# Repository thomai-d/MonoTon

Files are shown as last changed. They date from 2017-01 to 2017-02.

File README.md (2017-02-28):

# MonoTon
Arduino based step sequencer and software-synth

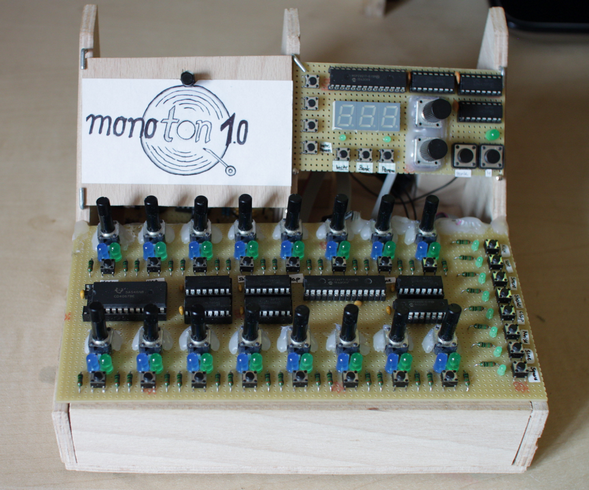
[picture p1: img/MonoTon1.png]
MonoTon1


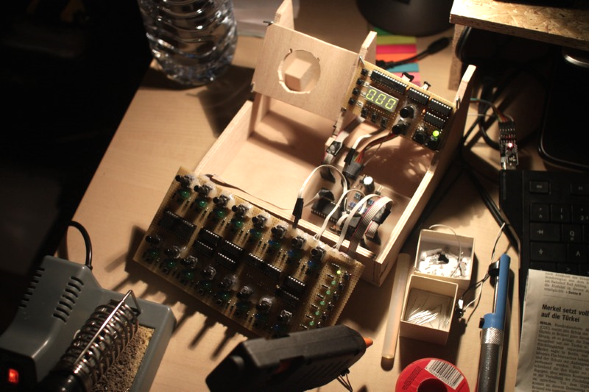
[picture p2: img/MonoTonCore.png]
MonotonCore


Video on youtube:

Youtube (http://www.youtube.com/watch?v=V6P4GdR-m2A)

[(Audio only)](https://github.com/thomai-d/MonoTon/blob/master/media/MonoTon1.mp3).

## Features
* 8 instruments (Kick, Hat, Snare, Shaker, Clap, Noise, Sine, Square)
* Each instrument has 4 banks a 16 steps each and can be muted
* Synthesis using 8bit wavetables
* 20000Hz sampling rate
* Master is filtered through analog high-pass filter (2pole)

## Hardware
* atmega1284 @ 16MHz using [Mighty1284 platform](https://github.com/maniacbug/mighty-1284p)
* lots of 74HC595 shift registers (for LEDs)
* MCP23S17 port extenders (for buttons)
* CD4067 multiplexer (for analog potis)
* R2R network for D/A conversion
* Some eagle files included

## Lessons learned while developing
* The analog inputs are quite noisy. De-noising uses quite much cpu.
* Don't ever solder this much wires by hand. PCB services are your friend.
* Prefer [DDS](http://interface.khm.de/index.php/lab/interfaces-advanced/arduino-dds-sinewave-generator/) over an R2R ladder.

## Open bugs / flaws
* Although the output is buffered by an opamp, the sound sounds distorted when using the PC's line in. If I conntect it directly to the speakers, the sound is quite clear.

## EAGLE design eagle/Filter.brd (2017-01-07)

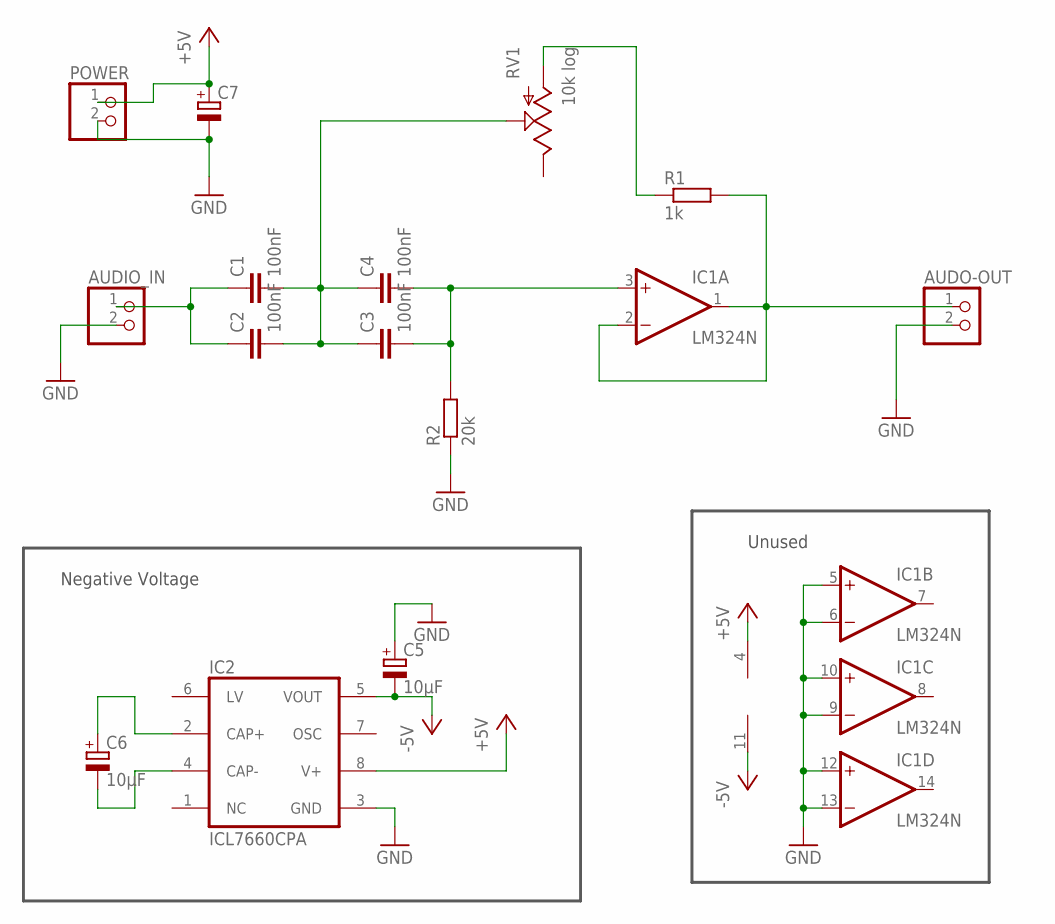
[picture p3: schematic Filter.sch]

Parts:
AUDIO_IN: PINHD-1X2; 1X02
AUDO-OUT: PINHD-1X2; 1X02
C1, C2, C3, C4: 100nF; C025-025X050
C5, C6: 10µF; E2,5-6
C7: CPOL-EUE2.5-6; E2,5-6
IC1: LM324N; DIL14
IC2: ICL7660CPA; DIL08
POWER: PINHD-1X2; 1X02
R1: 1k; 0207/7
R2: 20k; 0207/7
RV1: 10k log; ALPS_POT

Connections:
+5V: C7.+, IC1.4 (V+), IC2.8 (V+), POWER.1
-5V: C5.-, IC1.11 (V-), IC2.5 (VOUT)
GND: AUDIO_IN.2, AUDO-OUT.2, C5.+, C7.-, IC1.5 (+IN), IC1.6 (-IN), IC1.9 (-IN), IC1.10 (+IN), IC1.12 (+IN), IC1.13 (-IN), IC2.3 (GND), POWER.2, R2.1
unnamed: C3.2, C4.2, IC1.3 (+IN), R2.2
unnamed: AUDIO_IN.1, C1.1, C2.1
unnamed: C1.2, C2.2, C3.1, C4.1, RV1.P$2 (S)
unnamed: AUDO-OUT.1, IC1.1 (OUT), IC1.2 (-IN), R1.2
unnamed: R1.1, RV1.P$3 (A)
unnamed: C6.+, IC2.2 (CAP+)
unnamed: C6.-, IC2.4 (CAP-)

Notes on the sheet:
Unused
Negative Voltage

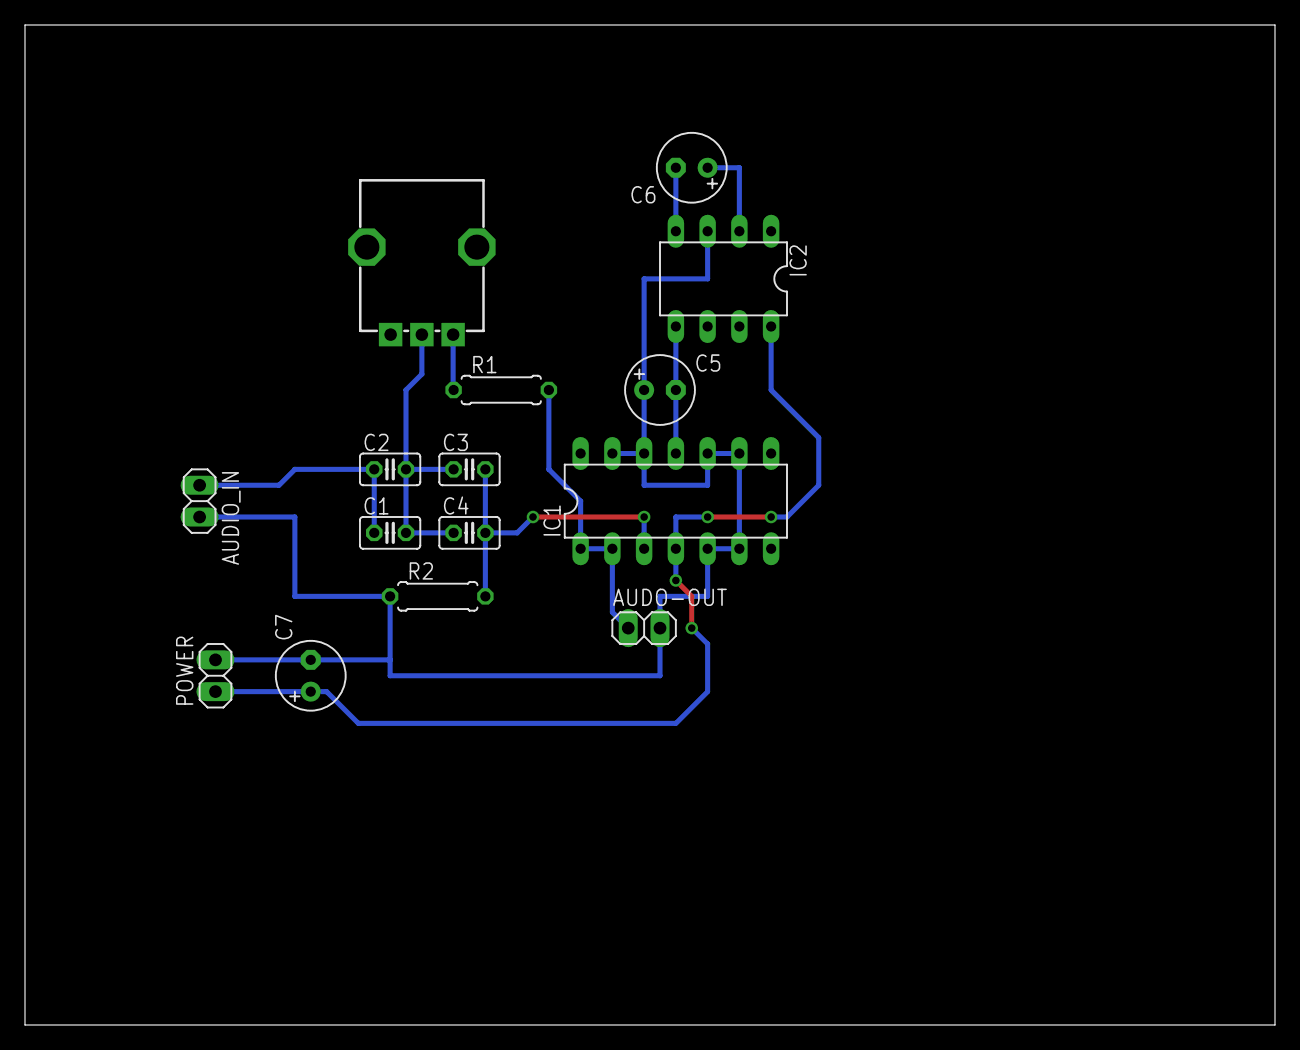
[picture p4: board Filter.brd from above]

Board: 2 copper layers, 100.0 x 80.0 mm, 15 parts (0 on the bottom side), 10 nets.

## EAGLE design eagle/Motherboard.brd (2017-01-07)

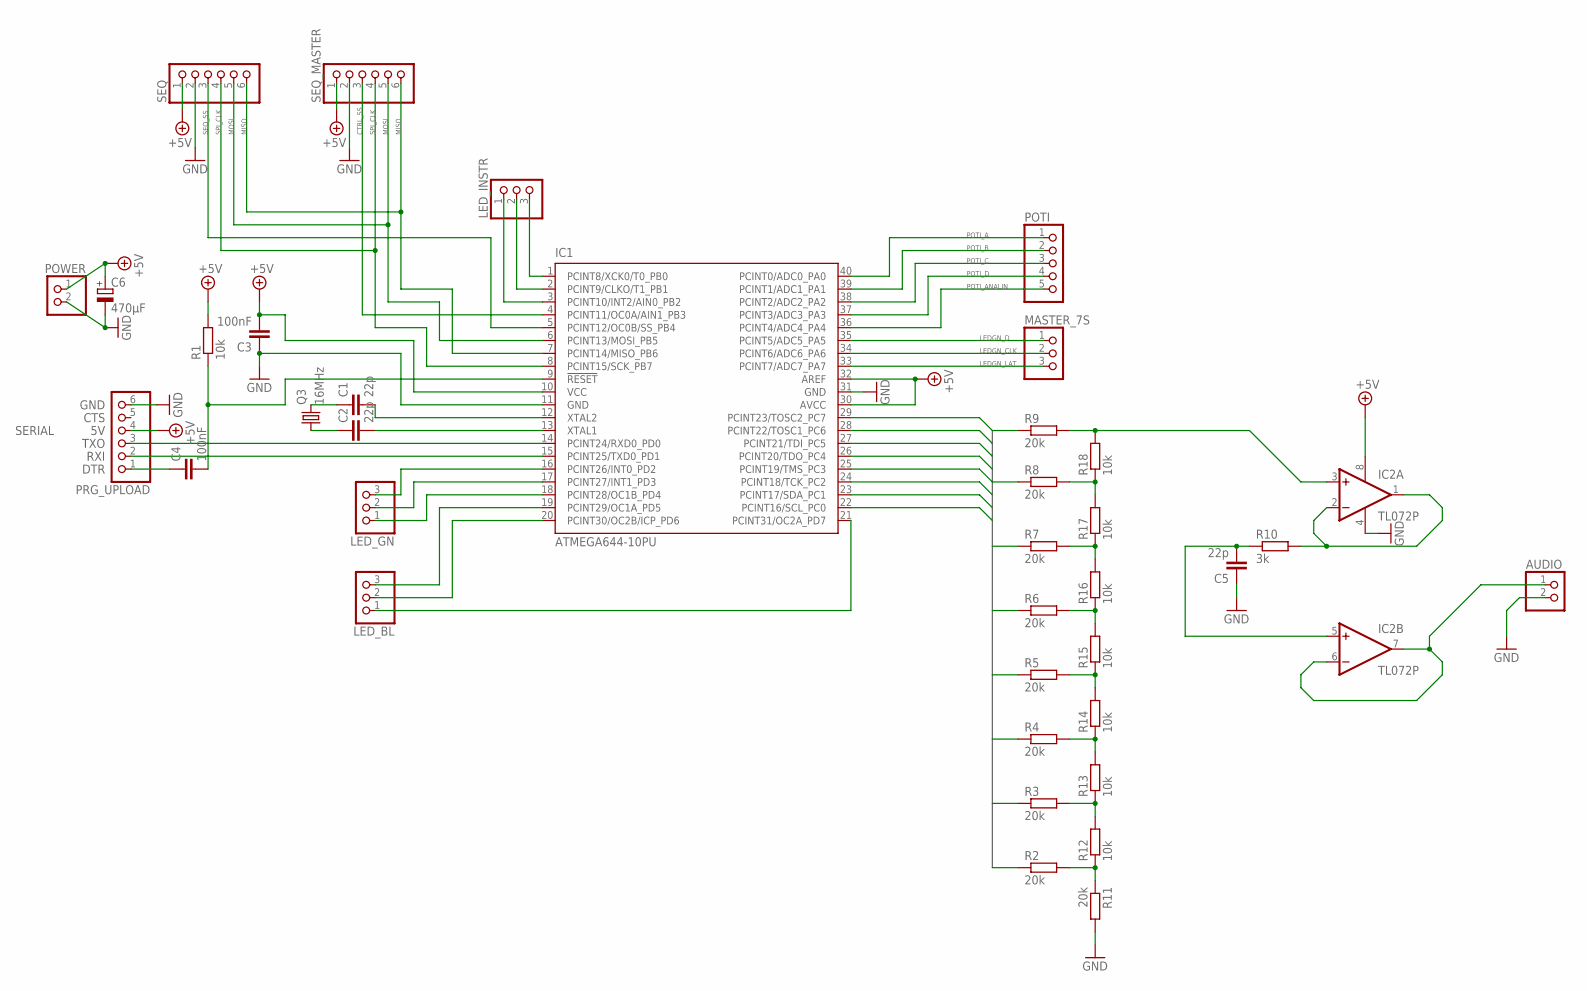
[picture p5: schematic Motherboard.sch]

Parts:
AUDIO: PINHD-1X2; 1X02
C1, C2, C5: 22p; C025-060X050
C3, C4: 100nF; C025-060X050
C6: 470µF; E3,5-10
IC1: ATMEGA644-10PU; DIL40
IC2: TL072P; DIL08
LED_BL: PINHD-1X3; 1X03
LED_GN: PINHD-1X3; 1X03
LED_INSTR: PINHD-1X3; 1X03
MASTER_7S: PINHD-1X3; 1X03
POTI: PINHD-1X5; 1X05
POWER: PINHD-1X2; 1X02
PRG_UPLOAD: PINHD-1X6; 1X06
Q3: 16MHz; HC18U-V
R1, R12, R13, R14, R15, R16, R17, R18: 10k; 0204/7
R2, R3, R4, R5, R6, R7, R8, R9, R11: 20k; 0204/7
R10: 3k; 0204/7
SEQ: PINHD-1X6; 1X06
SEQ_MASTER: PINHD-1X6; 1X06

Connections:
+5V: C3.2, C6.+, IC1.10 (VCC), IC1.30 (AVCC), IC1.32 (AREF), IC2.8 (V+), POWER.1, PRG_UPLOAD.4, R1.2, SEQ.1, SEQ_MASTER.1
CTRL_SS: IC1.4 (PCINT11/OC0A/AIN1_PB3), SEQ_MASTER.3
DA0: IC1.22 (PCINT16/SCL_PC0), R2.1
DA1: IC1.23 (PCINT17/SDA_PC1), R3.1
DA2: IC1.24 (PCINT18/TCK_PC2), R4.1
DA3: IC1.25 (PCINT19/TMS_PC3), R5.1
DA4: IC1.26 (PCINT20/TDO_PC4), R6.1
DA5: IC1.27 (PCINT21/TDI_PC5), R7.1
DA6: IC1.28 (PCINT22/TOSC1_PC6), R8.1
DA7: IC1.29 (PCINT23/TOSC2_PC7), R9.1
GND: AUDIO.2, C3.1, C5.1, C6.-, IC1.11 (GND), IC1.31 (GND), IC2.4 (V-), POWER.2, PRG_UPLOAD.6, R11.2, SEQ.2, SEQ_MASTER.2
LEDGN_CLK: IC1.34 (PCINT6/ADC6_PA6), MASTER_7S.2
LEDGN_D: IC1.35 (PCINT5/ADC5_PA5), MASTER_7S.1
LEDGN_LAT: IC1.33 (PCINT7/ADC7_PA7), MASTER_7S.3
MISO: IC1.7 (PCINT14/MISO_PB6), SEQ.6, SEQ_MASTER.6
MOSI: IC1.6 (PCINT13/MOSI_PB5), SEQ.5, SEQ_MASTER.5
unnamed: C1.1, Q3.2
unnamed: C2.1, Q3.1
unnamed: C2.2, IC1.13 (XTAL1)
unnamed: C1.2, IC1.12 (XTAL2)
unnamed: R3.2, R12.2, R13.1
unnamed: R4.2, R13.2, R14.1
unnamed: R5.2, R14.2, R15.1
unnamed: R6.2, R15.2, R16.1
unnamed: IC1.1 (PCINT8/XCK0/T0_PB0), LED_INSTR.3
unnamed: IC1.2 (PCINT9/CLKO/T1_PB1), LED_INSTR.2
unnamed: IC1.3 (PCINT10/INT2/AIN0_PB2), LED_INSTR.1
unnamed: R7.2, R16.2, R17.1
unnamed: R8.2, R17.2, R18.1
unnamed: R2.2, R11.1, R12.1
unnamed: IC2.3 (+IN), R9.2, R18.2
unnamed: IC2.1 (OUT), IC2.2 (-IN), R10.2
unnamed: IC1.16 (PCINT26/INT0_PD2), LED_GN.3
unnamed: IC1.17 (PCINT27/INT1_PD3), LED_GN.2
unnamed: IC1.18 (PCINT28/OC1B_PD4), LED_GN.1
unnamed: IC1.19 (PCINT29/OC1A_PD5), LED_BL.3
unnamed: IC1.20 (PCINT30/OC2B/ICP_PD6), LED_BL.2
unnamed: IC1.21 (PCINT31/OC2A_PD7), LED_BL.1
unnamed: C5.2, IC2.5 (+IN), R10.1
unnamed: AUDIO.1, IC2.6 (-IN), IC2.7 (OUT)
POTI_A: IC1.40 (PCINT0/ADC0_PA0), POTI.1
POTI_ANALIN: IC1.36 (PCINT4/ADC4_PA4), POTI.5
POTI_B: IC1.39 (PCINT1/ADC1_PA1), POTI.2
POTI_C: IC1.38 (PCINT2/ADC2_PA2), POTI.3
POTI_D: IC1.37 (PCINT3/ADC3_PA3), POTI.4
RESET: C4.2, IC1.9 (!RESET), R1.1
SEQ_SS: IC1.5 (PCINT12/OC0B/SS_PB4), SEQ.3
SPI_CLK: IC1.8 (PCINT15/SCK_PB7), SEQ.4, SEQ_MASTER.4
UPLOAD_DTR: C4.1, PRG_UPLOAD.1
UPLOAD_RXI: IC1.15 (PCINT25/TXD0_PD1), PRG_UPLOAD.2
UPLOAD_TXO: IC1.14 (PCINT24/RXD0_PD0), PRG_UPLOAD.3

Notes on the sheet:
GND
CTS
TXO
RXI
DTR
SERIAL

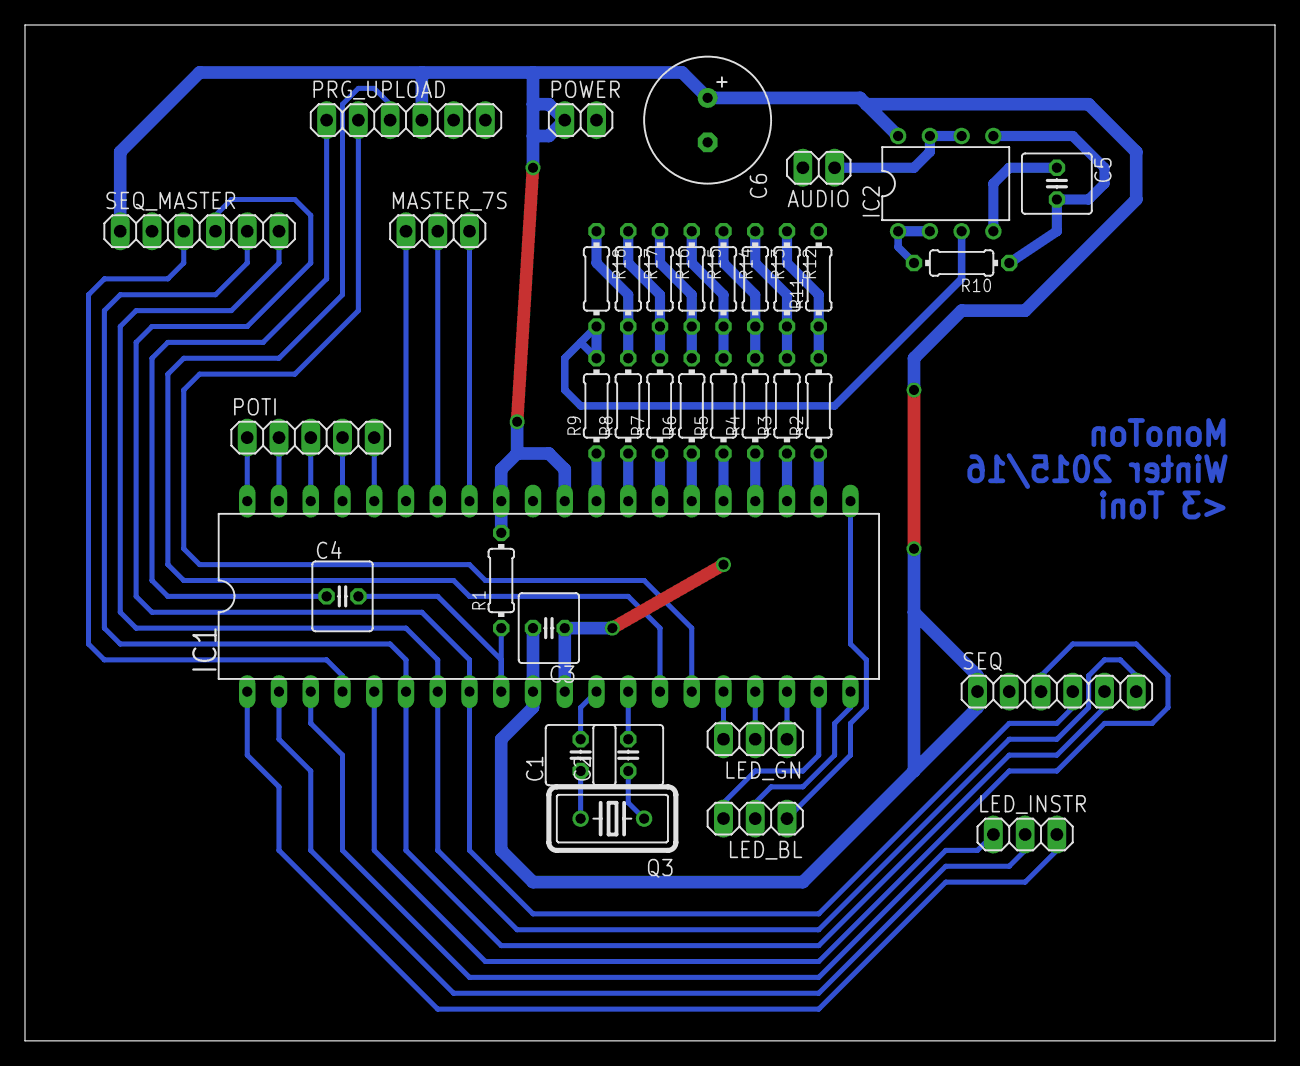
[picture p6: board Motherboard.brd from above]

Board: 2 copper layers, 100.0 x 81.3 mm, 37 parts (0 on the bottom side), 51 nets.

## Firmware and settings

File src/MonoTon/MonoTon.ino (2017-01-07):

#include "SPI.h"
#include "Configuration.h"
#include "System/SyncTimer.h"
#include "System/PerformanceTrace.h"
#include "Control/SequencerController.h"
#include "Hardware/AudioOut.h"
#include "Synthesis/InstrumentRack.h"
#include "System/TimerThree.h"
#include "Control/Sequencer.h"
#include "Hardware/SequencerDriver.h"

SequencerController seqCtrl;

SyncTimer timer16;
SyncTimer analogTimer;
SyncTimer controlTimer;

void NextSample();
void AnalogTimer();

void setup() {

	Serial.begin(115200);
	Serial.println("MonoTon 1.0");

	timer16.Start(60000 / 125 / 4, Timer16th);
	controlTimer.Start(CONTROL_RATE_MS, ControlTimer);
	analogTimer.Start(300, AnalogTimer);

	Timer3.initialize();
	Timer3.attachInterrupt(NextSample, 1000000 / SAMPLE_RATE);

	// Faster analog read
	bitSet(ADCSRA, ADPS2);
	bitClear(ADCSRA, ADPS1);
	bitClear(ADCSRA, ADPS0);

	seqCtrl.Initialize();
}

void Timer16th()
{
	seqCtrl.Tick16();
}

void ControlTimer()
{
	instrumentRack.ControlTick();
}

void AnalogTimer()
{
	seqCtrl.CheckAnalogInputs();
}

void loop() 
{
	timer16.Check();
	controlTimer.Check();
	analogTimer.Check();

	seqCtrl.CheckInputs();
	seqCtrl.UpdateOutputs();
	instrumentRack.ProcessSamples();
}

void NextSample()
{
	audioOut.SampleOut();
}

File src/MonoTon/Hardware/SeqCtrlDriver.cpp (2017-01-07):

#include "SeqCtrlDriver.h"
#include "../Hardware/Seg7.h"

#define POINT_BIT		0B1000

SeqCtrlDriver::SeqCtrlDriver() 
	: portExt0(SEQCTRL_PIN_CS, 0x0)
{
}

void SeqCtrlDriver::Initialize()
{
	pinMode(SEQCTRL_PIN_DS, OUTPUT);
	pinMode(SEQCTRL_PIN_STC, OUTPUT);
	pinMode(SEQCTRL_PIN_SHC, OUTPUT);
	
	portExt0.Initialize();
	portExt0.WriteByteChecked(IODIRA, 0B00111111);
	portExt0.WriteByteChecked(GPPUA, 0B00111111);
	portExt0.WriteByteChecked(IPOLA, 0B00111111);
	portExt0.WriteByteChecked(IODIRB, 0B01111111);
	portExt0.WriteByteChecked(GPPUB, 0B01111111);
	portExt0.WriteByteChecked(IPOLB, 0B01111111);
	portExt0.WriteByteChecked(OLATA, 0x0);
	portExt0.WriteByteChecked(OLATB, 0x0);

	this->ClearDisplay();
	this->SetHiLoLed(0, 0);
	this->SetTickLed(0);
	this->UpdateOutputs();

	this->lastButtonUpdate = millis();
}

void SeqCtrlDriver::Test()
{
	const int shortDelayTime = 50;
	const int longDelayTime = 150;

	this->SetTickLed(1);
	this->UpdateOutputs();
	delay(longDelayTime);
	this->SetTickLed(0);

	this->SetHiLoLed(0, 1);
	this->UpdateOutputs();
	delay(longDelayTime);

	this->SetHiLoLed(1, 0);
	this->UpdateOutputs();
	delay(longDelayTime);
	this->SetHiLoLed(0, 0);
	
	for (uint8_t i = 0; i < 9; i++)
	{
		this->SetDisplayRaw(_7segTest[i], 0, 0);
		this->UpdateOutputs();
		delay(shortDelayTime);
	}
	for (uint8_t i = 0; i < 9; i++)
	{
		this->SetDisplayRaw(0, _7segTest[i], 0);
		this->UpdateOutputs();
		delay(shortDelayTime);
	}
	for (uint8_t i = 0; i < 9; i++)
	{
		this->SetDisplayRaw(0, 0, _7segTest[i]);
		this->UpdateOutputs();
		delay(shortDelayTime);
	}
	this->SetDisplayRaw(0, 0, 0);
	this->UpdateOutputs();
}

void SeqCtrlDriver::ClearDisplay()
{
	this->SetDisplayRaw(0, 0, 0);
}

void SeqCtrlDriver::SetNumber(uint8_t number, bool pointA, bool pointB, bool pointC, uint16_t timeoutMs)
{
	uint8_t d1 = number % 10;
	number /= 10;
	uint8_t d2 = number % 10;
	number /= 10;
	uint8_t d3 = number % 10;
	this->SetDigits(d3, d2, d1, pointA, pointB, pointC, timeoutMs);
}

void SeqCtrlDriver::SetDigits(uint8_t d1, uint8_t d2, uint8_t d3, bool pointA, bool pointB, bool pointC, uint16_t timeoutMs)
{
	d1 = d1 < sizeof(_7segLookup) ? _7segLookup[d1] : 0;
	d2 = d2 < sizeof(_7segLookup) ? _7segLookup[d2] : 0;
	d3 = d3 < sizeof(_7segLookup) ? _7segLookup[d3] : 0;
	if (pointA) d1 |= POINT_BIT;
	if (pointB) d2 |= POINT_BIT;
	if (pointC) d3 |= POINT_BIT;
	this->SetDisplayRaw(d1, d2, d3);

	if (timeoutMs != 0)
	{
		this->SetDisplayTimeout(timeoutMs);
	}
	else
	{
		this->defSegA = d1;
		this->defSegB = d2;
		this->defSegC = d3;
	}
}

void SeqCtrlDriver::SetDisplay(uint32_t value, uint16_t timeoutMs)
{
	uint8_t d1 = GETA_SEG7(value);
	uint8_t d2 = GETB_SEG7(value);
	uint8_t d3 = GETC_SEG7(value);
	this->SetDisplayRaw(d1, d2, d3);

	if (timeoutMs != 0)
	{
		this->SetDisplayTimeout(timeoutMs);
	}
	else
	{
		this->defSegA = d1;
		this->defSegB = d2;
		this->defSegC = d3;
	}
}

void SeqCtrlDriver::SetDisplayTimeout(uint16_t timeoutMs)
{
	this->lastOutputUpdate = millis();
	this->displayTimeout = timeoutMs;
}

void SeqCtrlDriver::SetTickLed(bool state)
{
	this->tickState = state;
	this->ext0RefreshNeeded = true;
}

void SeqCtrlDriver::SetHiLoLed(bool lo, bool hi)
{
	this->hiState = hi;
	this->loState = lo;
	this->ext0RefreshNeeded = true;
}

void SeqCtrlDriver::CheckInputs()
{
	uint8_t gpioA = portExt0.ReadByte(GPIOA) & 0B00111111;
	uint8_t gpioB = portExt0.ReadByte(GPIOB) & 0B01111111;

	// Check rotary buttons
	int8_t rot1Delta = rot1.Process(bitRead(gpioA, EXT0A_ROT1_A), bitRead(gpioA, EXT0A_ROT1_B));
	int8_t rot2Delta = rot2.Process(bitRead(gpioA, EXT0A_ROT2_A), bitRead(gpioA, EXT0A_ROT2_B));
	this->rot1Value += rot1Delta;
	this->rot2Value += rot2Delta;

	uint32_t now = millis();
	uint16_t delta = TIME_DELTA_MS(now, this->lastButtonUpdate);
	this->lastButtonUpdate = now;
	if (this->buttonCheckDelay > delta)
	{
		this->buttonCheckDelay -= delta;
	}
	else
	{
		this->buttonCheckDelay = BUTTON_DEBOUNCE_MILLIS;

		// GPIOA
		for (uint8_t i = 4; i <= 5; i++)
		{
			bool state = bitRead(gpioA, i);
			bool lastState = bitRead(this->stateA, i);
			if (!lastState && state)
			{
				bitSet(this->buttonPressedA, i);
			}
		}

		// GPIOB
		for (uint8_t i = 0; i <= 6; i++)
		{
			bool state = bitRead(gpioB, i);
			bool lastState = bitRead(this->stateB, i);
			if (!lastState && state)
			{
				bitSet(this->buttonPressedB, i);
			}
		}

		this->stateA = gpioA;
		this->stateB = gpioB;
	}

	// DEBUG
	if (rot1Delta != 0)
	{
		this->SetNumber(this->rot1Value, false, true, false, 500);
		this->bpmChanged = true;
	}

	if (rot2Delta != 0)
	{
		this->SetNumber(this->rot2Value, false, false, true, 500);
	}
}

void SeqCtrlDriver::UpdateOutputs()
{
	if (this->ext0RefreshNeeded)
	{
		this->portExt0.WriteByte(OLATB, this->tickState << EXT0B_LED_TICK);
		this->portExt0.WriteByte(OLATA, (this->hiState << EXT0A_LED_HI) | (this->loState << EXT0A_LED_LO));
		this->ext0RefreshNeeded = false;
	}

	if (this->seg8RefreshNeeded)
	{
		shiftOut(SEQCTRL_PIN_DS, SEQCTRL_PIN_SHC, MSBFIRST, this->segC);
		shiftOut(SEQCTRL_PIN_DS, SEQCTRL_PIN_SHC, MSBFIRST, this->segB);
		shiftOut(SEQCTRL_PIN_DS, SEQCTRL_PIN_SHC, MSBFIRST, this->segA);
		digitalWrite(SEQCTRL_PIN_STC, LOW);
		digitalWrite(SEQCTRL_PIN_STC, HIGH);
		this->seg8RefreshNeeded = false;
	}

	if (this->displayTimeout > 0)
	{
		uint32_t now = millis();
		uint16_t delta = TIME_DELTA_MS(this->lastOutputUpdate, now);

		if (this->displayTimeout <= delta)
		{
			this->displayTimeout = 0;
			this->RestoreDisplay();
		}
		else
		{
			this->lastOutputUpdate = now;
			this->displayTimeout -= delta;
		}
	}
}

void SeqCtrlDriver::SetDisplayRaw(uint8_t d1, uint8_t d2, uint8_t d3)
{
	this->segA = d1;
	this->segB = d2;
	this->segC = d3;
	this->seg8RefreshNeeded = true;
}

void SeqCtrlDriver::RestoreDisplay()
{
	this->segA = this->defSegA;
	this->segB = this->defSegB;
	this->segC = this->defSegC;
	this->seg8RefreshNeeded = true;
}

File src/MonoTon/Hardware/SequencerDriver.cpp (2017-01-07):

#include "SequencerDriver.h"

// todo verschieben
void shiftOut16(uint8_t dataPin, uint8_t clockPin, uint8_t storePin, uint16_t data)
{
	digitalWrite(storePin, LOW);
	shiftOut(dataPin, clockPin, MSBFIRST, data >> 8);
	shiftOut(dataPin, clockPin, MSBFIRST, data & 0xff);
	digitalWrite(storePin, HIGH);
}

SequencerDriver::SequencerDriver()
	: portExtInstr(SEQ_PIN_BTN_CS, 0),
	  portExtSeq(SEQ_PIN_BTN_CS, 1)
{
}

void SequencerDriver::Initialize()
{
	pinMode(SEQ_PIN_POTI_A, OUTPUT);
	pinMode(SEQ_PIN_POTI_B, OUTPUT);
	pinMode(SEQ_PIN_POTI_C, OUTPUT);
	pinMode(SEQ_PIN_POTI_D, OUTPUT);
	pinMode(SEQ_PIN_LEDGN_D, OUTPUT);
	pinMode(SEQ_PIN_LEDGN_CLK, OUTPUT);
	pinMode(SEQ_PIN_LEDGN_LAT, OUTPUT);
	pinMode(SEQ_PIN_LEDINSTR_D, OUTPUT);
	pinMode(SEQ_PIN_LEDINSTR_CLK, OUTPUT);
	pinMode(SEQ_PIN_LEDINSTR_LAT, OUTPUT);
	pinMode(SEQ_PIN_LEDBL_D, OUTPUT);
	pinMode(SEQ_PIN_LEDBL_CLK, OUTPUT);
	pinMode(SEQ_PIN_LEDBL_LAT, OUTPUT);

	this->SetBlueLEDs(0);
	this->SetGreenLEDs(0);
	this->SetInstrumentLEDs(0);

	this->portExtSeq.Initialize();
	this->portExtSeq.WriteByte(GPPUA, 0xff);
	this->portExtSeq.WriteByte(GPPUB, 0xff);
	this->portExtSeq.WriteByte(IODIRA, 0xff);
	this->portExtSeq.WriteByte(IODIRB, 0xff);
	this->portExtSeq.WriteByte(IPOLA, 0xff);
	this->portExtSeq.WriteByte(IPOLB, 0xff);
	this->portExtSeq.WriteByte(IOCON1, HAEN);
	this->portExtInstr.Initialize();
	this->portExtInstr.WriteByte(GPPU, 0xff);
	this->portExtInstr.WriteByte(IODIR, 0xff);
	this->portExtInstr.WriteByte(IPOL, 0xff);
	this->portExtInstr.WriteByte(IOCON, HAEN);

	this->SetInstrumentLEDs(1);
}

void SequencerDriver::Test()
{
	uint16_t counter = 1;
	do
	{
		this->SetBlueLEDs(counter);
		this->SetGreenLEDs(counter);
		delay(100);
		counter <<= 1;
	} while (counter != 0);

	this->SetBlueLEDs(0);
	this->SetGreenLEDs(0);
	counter = 0B100000000;
	do
	{
		this->SetInstrumentLEDs(counter);
		delay(100);
		counter >>= 1;
	} while (counter != 0);


	this->SetInstrumentLEDs(0);
}

void SequencerDriver::CheckInputs()
{
	uint8_t instrBtns = this->portExtInstr.ReadByte(GPIO);
	uint8_t seqBtnsA = this->portExtSeq.ReadByte(GPIOA);
	uint8_t seqBtnsB = this->portExtSeq.ReadByte(GPIOB);
	uint16_t seqBtns = ((uint16_t)seqBtnsB << 8) + seqBtnsA;
	bool changed = false;

	if (instrBtns != this->instrBtnStates)
	{
		for (uint8_t i = 0; i < 8; i++)
		{
			bool lastState = bitRead(this->instrBtnStates, i);
			bool currentState = bitRead(instrBtns, i);
			if (!lastState && currentState)
			{
				this->selection = i;
				this->selectionChanged = true;
				break;
			}
		}

		this->instrBtnStates = instrBtns;
	}

	if (seqBtns != this->seqBtnStates)
	{
		for (uint8_t i = 0; i < 16; i++)
		{
			bool lastState = bitRead(this->seqBtnStates, i);
			bool currentState = bitRead(seqBtns, i);
			if (!lastState && currentState)
			{
				// pressed
				bitWrite(this->sequencerSteps, i, !bitRead(this->sequencerSteps, i));
				this->sequencerStepsChanged = true;
				this->SetGreenLEDs(this->sequencerSteps);
			}
		}

		this->seqBtnStates = seqBtns;
	}
}

void SequencerDriver::SetStep(uint8_t step)
{
	this->SetBlueLEDs((uint16_t)1 << step);
	delay(1);
	this->SetBlueLEDs(0);
}

void SequencerDriver::SetSteps(uint16_t bank)
{
	this->sequencerSteps = bank;
	this->SetGreenLEDs(this->sequencerSteps);
}

uint8_t SequencerDriver::GetValue(uint8_t step)
{
	digitalWrite(SEQ_PIN_POTI_A, bitRead(step, 0));
	digitalWrite(SEQ_PIN_POTI_B, bitRead(step, 1));
	digitalWrite(SEQ_PIN_POTI_C, bitRead(step, 2));
	digitalWrite(SEQ_PIN_POTI_D, bitRead(step, 3));
	return analogRead(A4) / 16;
}

bool SequencerDriver::IsDebugButtonPressed()
{
	return (this->portExtInstr.ReadByte(GPIO) > 0);
}

void SequencerDriver::SetBlueLEDs(uint16_t value)
{
	shiftOut16(SEQ_PIN_LEDBL_D, SEQ_PIN_LEDBL_CLK, SEQ_PIN_LEDBL_LAT, value);
}

void SequencerDriver::SetGreenLEDs(uint16_t value)
{
	shiftOut16(SEQ_PIN_LEDGN_D, SEQ_PIN_LEDGN_CLK, SEQ_PIN_LEDGN_LAT, value);
}

void SequencerDriver::SetInstrumentLEDs(uint8_t value)
{
	digitalWrite(SEQ_PIN_LEDINSTR_LAT, LOW);
	shiftOut(SEQ_PIN_LEDINSTR_D, SEQ_PIN_LEDINSTR_CLK, MSBFIRST, value);
	digitalWrite(SEQ_PIN_LEDINSTR_LAT, HIGH);
}

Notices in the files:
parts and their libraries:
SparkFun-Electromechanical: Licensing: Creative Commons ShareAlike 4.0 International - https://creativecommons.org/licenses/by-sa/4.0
